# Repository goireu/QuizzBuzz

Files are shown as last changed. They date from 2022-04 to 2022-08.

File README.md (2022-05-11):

# QuizzBuzz

Qwizzzzz Buzzzzz Weeeeezzzzzzz

This is a project to turn widespread ["got talent" like quiz buzzers](https://www.amazon.fr/RanDal-Buzzer-Alarme-Loterie-Lumi%C3%A8re/dp/B082Y17FFG) and an iOS-based device into a fun wireless quiz game.

Requirements:
- An iOS device (iPhone/iPad) with iOS 15+
- Spotify app installed on the device (a paid subscription is strongly recommended to avoid ads and allow for skipping songs)
- Some buzzers
- XCode for iOS 15+ for the Quizzer app
- KiCad for the PCB files
- nRF Connect SDK 1.9.1+ for the firmware

# Buzzer HowTo

Press the Buzzer for 3 to power it up, indicator will flash quickly while it isn't connected to a QuizzBuzz app.
When connection establishes the indicator will switch off.

After 30 seconds unconnected, the Buzzer will automatically power off.
After 30 minutes connected without buzzing, the Buzzer will also automatically power off.

# Game HowTo

When the game starts, everyone is allowed to buzz while the music is playing. The fastest buzzing team will have its buzzer blinking (much slower than when unconnected) and can try a guess.
If the guess is incorrect, and game is configured not to allow multiple answers, the indicator will stay lit and you can't buzz until next song.
Upon moving to next song, indicators will switch off and everyone can play again.

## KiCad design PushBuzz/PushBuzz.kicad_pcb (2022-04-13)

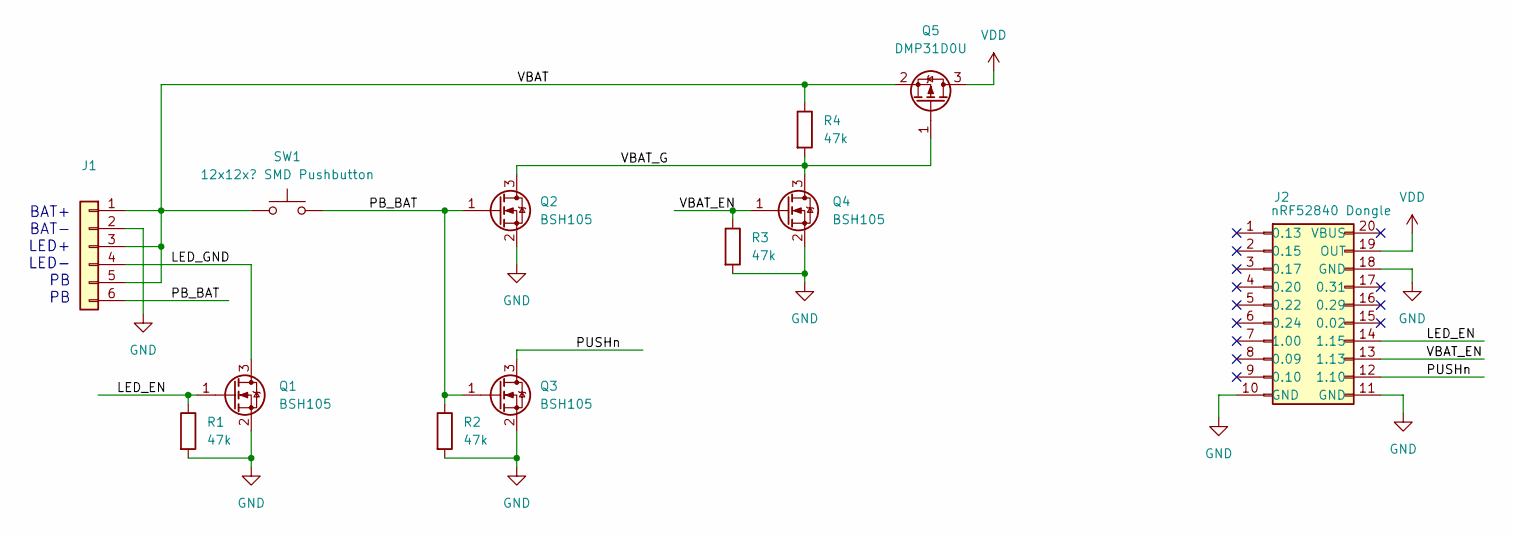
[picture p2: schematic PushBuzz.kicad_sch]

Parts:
J1: (no value)
J2: nRF52840 Dongle; nRF52840-Dongle
Q1, Q2, Q3, Q4: BSH105; SOT-23_Handsoldering
Q5: DMP31D0U; SOT-23_Handsoldering
R1, R2, R3, R4: 47k; R_0603_1608Metric_Pad0.98x0.95mm_HandSolder
SW1: 12x12x? SMD Pushbutton; 12x12 Pushbutton

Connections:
/LED_EN: J2.14 (1.15), Q1.1 (G), R1.1
/LED_GND: J1.4, Q1.3 (D)
/PB_BAT: J1.6, Q2.1 (G), Q3.1 (G), R2.1, SW1.2
/PUSHn: J2.12 (1.10), Q3.3 (D)
/VBAT: J1.1, J1.3, J1.5, Q5.2 (S), R4.1, SW1.1
/VBAT_EN: J2.13 (1.13), Q4.1 (G), R3.1
/VBAT_G: Q2.3 (D), Q4.3 (D), Q5.1 (G), R4.2
GND: J1.2, J2.10 (GND), J2.11 (GND), J2.18 (GND), Q1.2 (S), Q2.2 (S), Q3.2 (S), Q4.2 (S), R1.2, R2.2, R3.2
VDD: J2.19 (OUT), Q5.3 (D)

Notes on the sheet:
BAT+ BAT- LED+ LED- PB PB

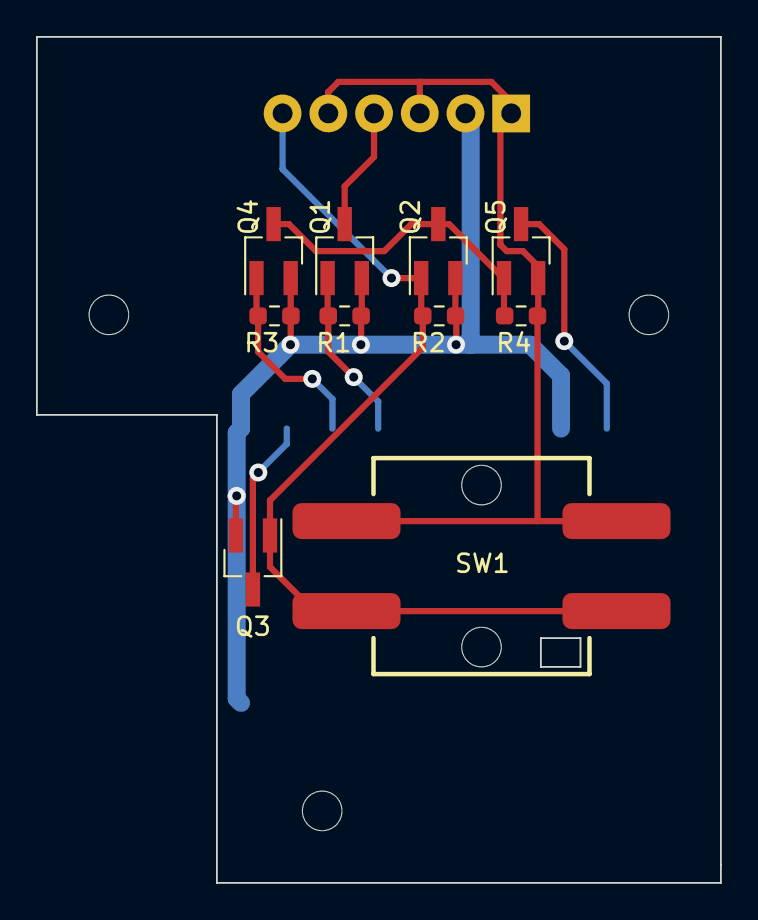
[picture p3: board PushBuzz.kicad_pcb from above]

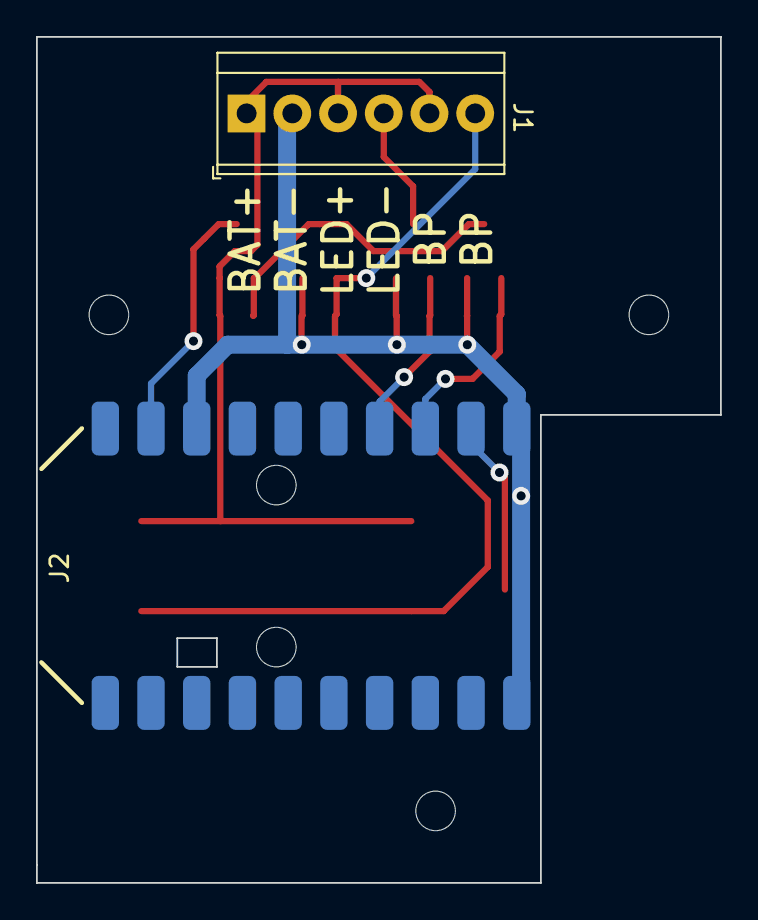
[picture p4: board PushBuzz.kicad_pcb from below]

Board: 2 copper layers, 38.0 x 47.0 mm, 12 parts (2 on the bottom side), 9 nets.

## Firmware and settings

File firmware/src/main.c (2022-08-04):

/*
 * Copyright (c) 2016 Intel Corporation.
 *
 * SPDX-License-Identifier: Apache-2.0
 */

#include "app.h"
#include "battery.h"

#include <usb/usb_device.h>
#include <drivers/uart.h>

BUILD_ASSERT(DT_NODE_HAS_COMPAT(DT_CHOSEN(zephyr_console), zephyr_cdc_acm_uart),
	     "Console device is not ACM CDC UART device");

void app_process();

void main(void)
{
	if (!pwr_init())
		NVIC_SystemReset();

#ifdef DEBUG
	if (usb_enable(NULL)) {
		return;
	}
	printk("[MAIN] USB initialized\n");

	// Wait for debug port to be opened
	const struct device *dev = DEVICE_DT_GET(DT_CHOSEN(zephyr_console));
	uint32_t dtr = 0;
	while (!dtr) {
		uart_line_ctrl_get(dev, UART_LINE_CTRL_DTR, &dtr);
		k_sleep(K_MSEC(100));
	}
#endif

	if (!ble_init())
		NVIC_SystemReset();
	if (!button_init())
		NVIC_SystemReset();
	if (!led_init())
		NVIC_SystemReset();
	if (!battery_init())
		NVIC_SystemReset();

	while (app_is_alive())
	{
		app_process();
		battery_process();
		led_process();

		// Get back to sleep for 100ms
		k_sleep(K_MSEC(100));
	}

	printk("[MAIN] Shutting down\n");
	led_set(false);
	if (!pwr_down())
		NVIC_SystemReset();

	// For non patched modules
	k_sleep(K_MSEC(5000));
}

static unsigned long app_timeout = KEEPALIVE_UNCONNECTED;
void app_reset_keep_alive(unsigned long timeout)
{
	app_timeout = timeout;
}

void app_process()
{
	static char prescaler = 10; // App tick is 100ms

	prescaler--;
	if (!prescaler) {
		prescaler = 10;
		if (app_timeout)
			app_timeout--;
	}
}

bool app_is_alive()
{
	return app_timeout != 0;
}

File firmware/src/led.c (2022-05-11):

#include "app.h"
#include <drivers/gpio.h>

/* This is the embedded LED. */
#define LED0_NODE DT_ALIAS(led0)
#define LED0	    DT_GPIO_LABEL(LED0_NODE, gpios)
#define LED0_PIN	DT_GPIO_PIN(LED0_NODE, gpios)
#define LED0_FLAGS	DT_GPIO_FLAGS(LED0_NODE, gpios)
static const struct device *led0_dev;

/* This is the buzzer indicator LED. */
#define LED1_NODE DT_ALIAS(led1)
#define LED1	    DT_GPIO_LABEL(LED1_NODE, gpios)
#define LED1_PIN	DT_GPIO_PIN(LED1_NODE, gpios)
#define LED1_FLAGS	DT_GPIO_FLAGS(LED1_NODE, gpios)
static const struct device *led1_dev;

static unsigned int led_prescaler = 0;
static unsigned int led_blink_counter = 0;
static bool led_on = false;

bool led_init(void)
{
	int ret;

    // LED0
	led0_dev = device_get_binding(LED0);
	if (led0_dev == NULL) {
        printk("[LED] Led 0 not found\n");
		return false;
	}
	ret = gpio_pin_configure(led0_dev, LED0_PIN, GPIO_OUTPUT_ACTIVE | LED0_FLAGS);
	if (ret < 0) {
        printk("[LED] Can't configure led 0\n");
		return false;
	}
    gpio_pin_set(led0_dev, LED0_PIN, 0); // Inverted logic is handled at driver level
    printk("[LED] Configured Led 0\n");
    
    // LED1
	led1_dev = device_get_binding(LED1);
	if (led1_dev == NULL) {
        printk("[LED] Led 1 not found\n");
		return false;
	}
	ret = gpio_pin_configure(led1_dev, LED1_PIN, GPIO_OUTPUT_ACTIVE | LED1_FLAGS);
	if (ret < 0) {
        printk("[LED] Can't configure led 1\n");
		return false;
	}
    gpio_pin_set(led1_dev, LED1_PIN, 0);
    printk("[LED] Configured Led 1\n");

    return true;
}

void led_set(bool on)
{
    gpio_pin_set(led0_dev, LED0_PIN, on ? 1 : 0); // Inverted logic is handled at driver level
    gpio_pin_set(led1_dev, LED1_PIN, on ? 1 : 0);
    led_on = on;
}

void led_activate(unsigned char cycles)
{
    // Switch off instantly
    if (!cycles) {
        led_set(false);
        led_blink_counter = 0; // Stop the blinking process
    }
    // Switch on without blinking
    else if (cycles == 0xFF) {
        led_set(true);
        led_blink_counter = 0; // Stop the blinking process
    }
    // For all other values, start blinking the required time
    else {
        led_prescaler = 0; // Trigger led blinking instantly
        led_blink_counter = cycles * 2; // Let led blink
    }
}

void led_process(void)
{
    // Blink quickly while BLE is not yet paired
    if (!ble_is_connected()) {
        led_set(!led_on);
    }
    // Perform what Quizzer app told us to do
    else  {
        if (!led_prescaler) {
            led_prescaler = LED_BLINK_INTERVAL;

            if (led_blink_counter) {
                printk("LED BlINK %s\n", led_on ? "on" : "off");
                led_blink_counter--;
                led_set(!led_on);
            }
        }
        led_prescaler--;
    }
}

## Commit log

2022-04-13 PCB v1
    [PushBuzz.kicad_pcb, PushBuzz.kicad_sch]
2022-04-27 Add support for complex LED indications
    Includes:
    - BT disconnected
    - Buzzer can't play
    - Buzzer selected
    [button.c, led.c, main.c]
2022-05-11 Add alternate references
    [PushBuzz.kicad_sch]
2022-05-11 Add support for power switch
    Also adjust coding style
2022-08-04 Prevent infinite loop rebooting for not-yet-patched modules
    [main.c]
